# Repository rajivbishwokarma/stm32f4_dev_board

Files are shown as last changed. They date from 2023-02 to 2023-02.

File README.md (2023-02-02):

# STM32F405RGT6 Development Board KiCAD Design Files

## Introduction
This repository contains a development board for STM32F405RGT6 microcontroller.

## Circuit Schematic
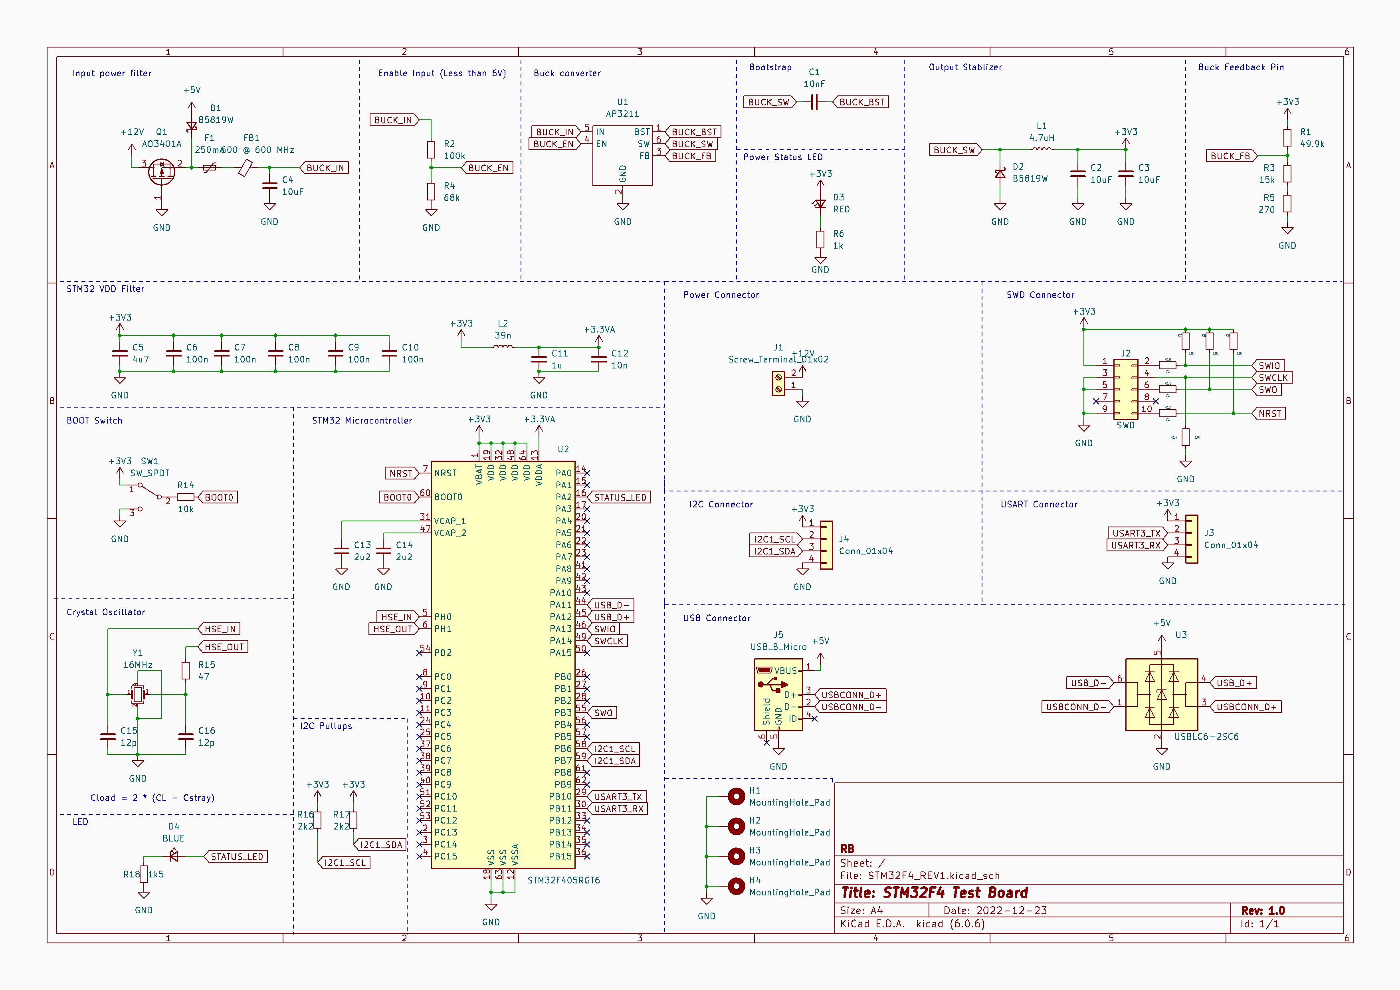
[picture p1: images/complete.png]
Circuit Schematic


## PCB and 3D View
<p align="left">
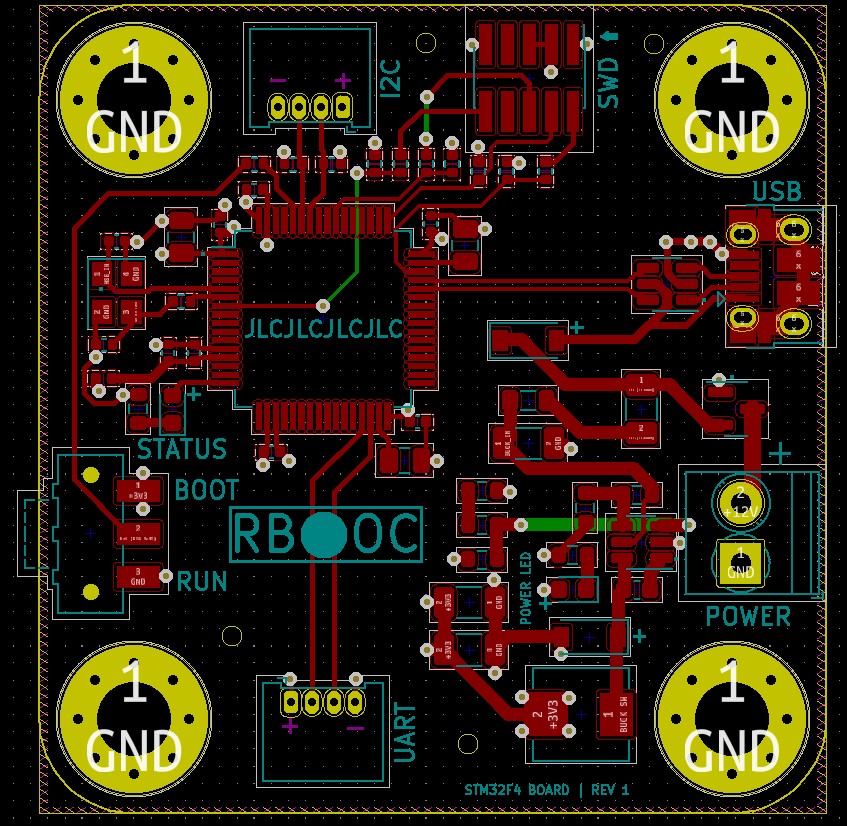
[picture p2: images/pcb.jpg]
    
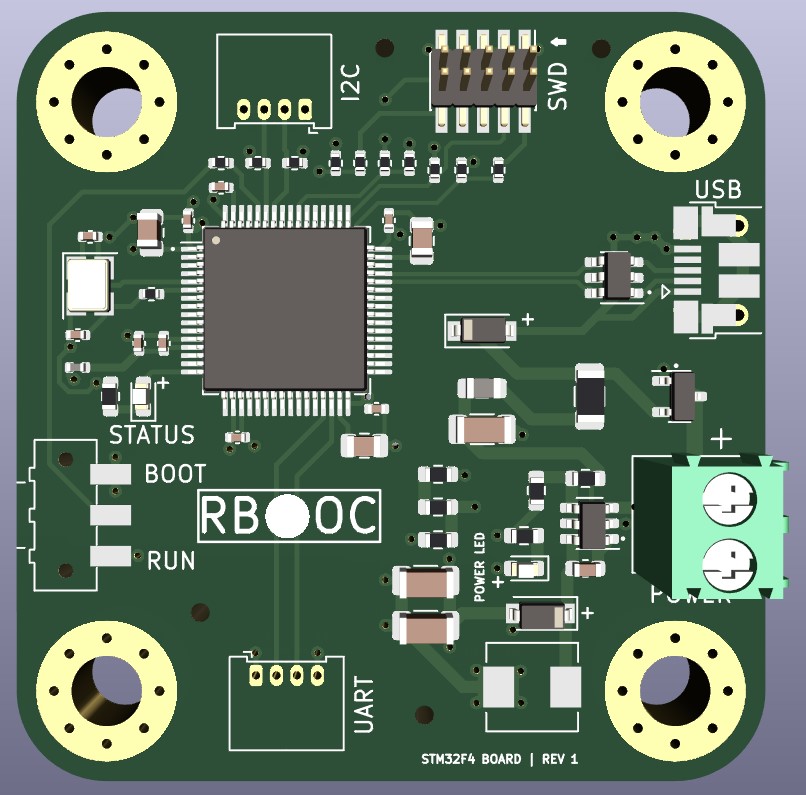
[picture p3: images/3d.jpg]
    
</p>

## Microcontroller
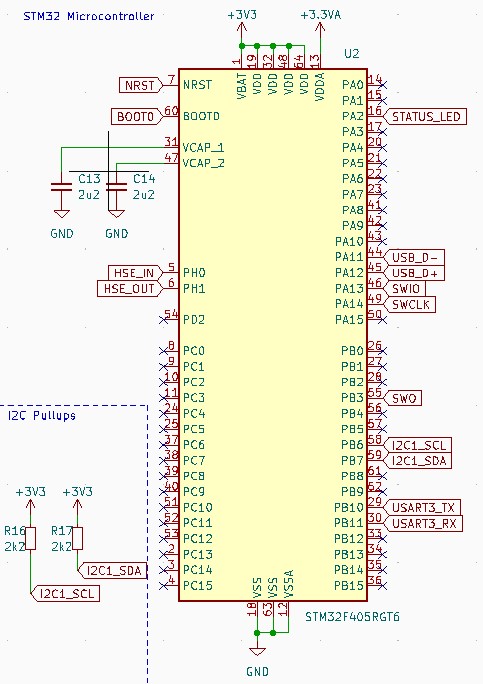
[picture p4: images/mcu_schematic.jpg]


## Buck Converter and SWD Interface
<p align="left">
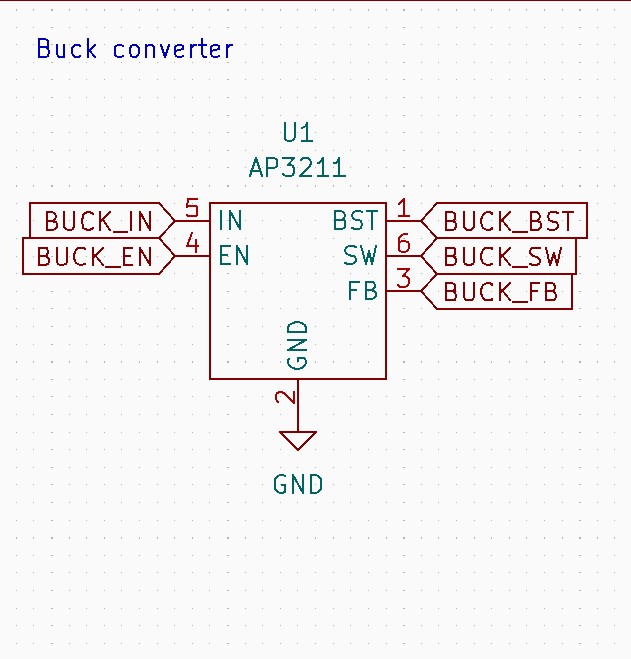
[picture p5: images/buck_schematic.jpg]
    
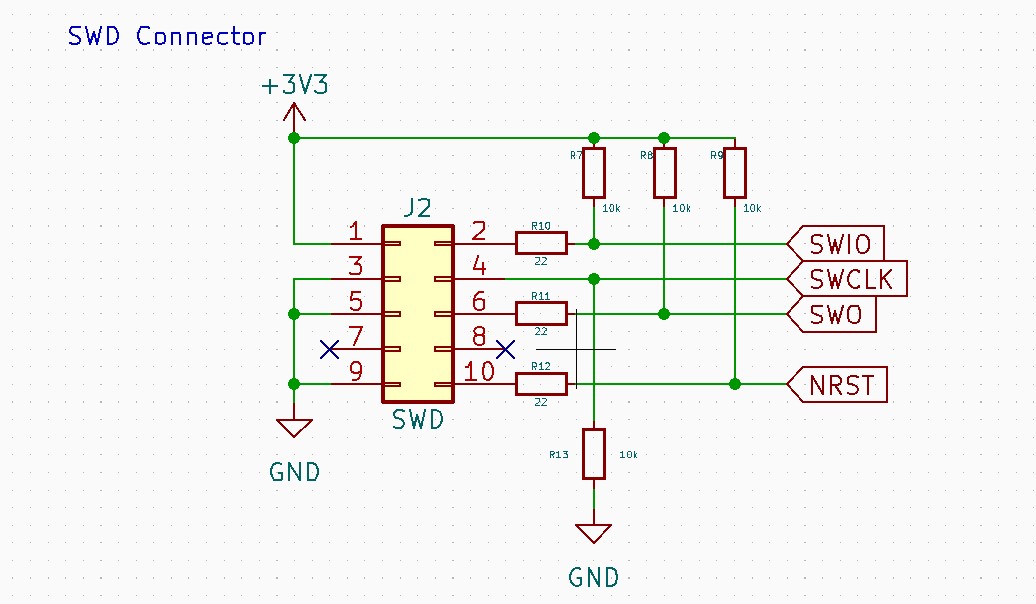
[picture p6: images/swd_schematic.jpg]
    
</p>

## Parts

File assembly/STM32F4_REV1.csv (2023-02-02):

Comment | Designator | Footprint | LCSC
10nF | C1 | Capacitor_SMD:C_0603_1608Metric | C282516
1u | C11 | Capacitor_SMD:C_0402_1005Metric | C106254
10n | C12 | Capacitor_SMD:C_0402_1005Metric | C783637
2u2 | C13,C14 | Capacitor_SMD:C_0805_2012Metric | C105486
12p | C15,C16 | Capacitor_SMD:C_0402_1005Metric | C147414
10uF | C2,C3,C4 | Capacitor_SMD:C_1206_3216Metric | C165101
4u7 | C5 | Capacitor_SMD:C_0805_2012Metric | C131057
100n | C6,C7,C8,C9,C10 | Capacitor_SMD:C_0402_1005Metric | C106204
B5819W | D1,D2 | Diode_SMD:D_SOD-123 | C908224
RED | D3 | LED_SMD:LED_0603_1608Metric | C84263
BLUE | D4 | LED_SMD:LED_0603_1608Metric | C375575
250mA | F1 | Fuse:Fuse_1206_3216Metric | C182446
600 @ 600 MHz | FB1 | Inductor_SMD:L_0805_2012Metric | C82155
MountingHole_Pad | H1,H2,H3,H4 | MountingHole:MountingHole_4.3mm_M4_Pad_Via
Screw_Terminal_01x02 | J1 | TerminalBlock_Phoenix:TerminalBlock_Phoenix_PT-1,5-2-3.5-H_1x02_P3.50mm_Horizontal | C395882
SWD | J2 | Connector_PinHeader_1.27mm:PinHeader_2x05_P1.27mm_Vertical_SMD | C5142425
Conn_01x04 | J3,J4 | Connector_Molex:Molex_PicoBlade_53048-0410_1x04_P1.25mm_Horizontal
USB_B_Micro | J5 | Connector_USB:USB_Micro-B_Amphenol_10103594-0001LF_Horizontal | C598519
10uH | L1 | Inductor_SMD:L_Sunlord_MWSA0518_5.4x5.2mm | C408349
39n | L2 | Inductor_SMD:L_0402_1005Metric | C142231
AO3401A | Q1 | Package_TO_SOT_SMD:SOT-23 | C347476
49.9k | R1 | Resistor_SMD:R_0603_1608Metric | C881902
22 | R10,R11,R12 | Resistor_SMD:R_0402_1005Metric | C102894
47 | R15 | Resistor_SMD:R_0402_1005Metric | C11930
2k2 | R16,R17 | Resistor_SMD:R_0402_1005Metric | C114762
1k5 | R18 | Resistor_SMD:R_0603_1608Metric | C140221
100k | R2 | Resistor_SMD:R_0603_1608Metric | C217279
15k | R3 | Resistor_SMD:R_0603_1608Metric | C285208
68k | R4 | Resistor_SMD:R_0603_1608Metric | C177676
270 | R5 | Resistor_SMD:R_0603_1608Metric | C209092
1k | R6 | Resistor_SMD:R_0603_1608Metric | C216905
10k | R7,R8,R9,R13,R14 | Resistor_SMD:R_0402_1005Metric | C406733
SW_SPDT | SW1 | Button_Switch_SMD:SW_SPDT_CK-JS102011SAQN | C221660
AP3211 | U1 | Package_TO_SOT_SMD:SOT-23-6 | C154863
STM32F405RGT6 | U2 | Package_QFP:LQFP-64_10x10mm_P0.5mm | C15742
USBLC6-2SC6 | U3 | Package_TO_SOT_SMD:SOT-23-6 | C7519
16MHz | Y1 | Crystal:Crystal_SMD_3225-4Pin_3.2x2.5mm | C13738

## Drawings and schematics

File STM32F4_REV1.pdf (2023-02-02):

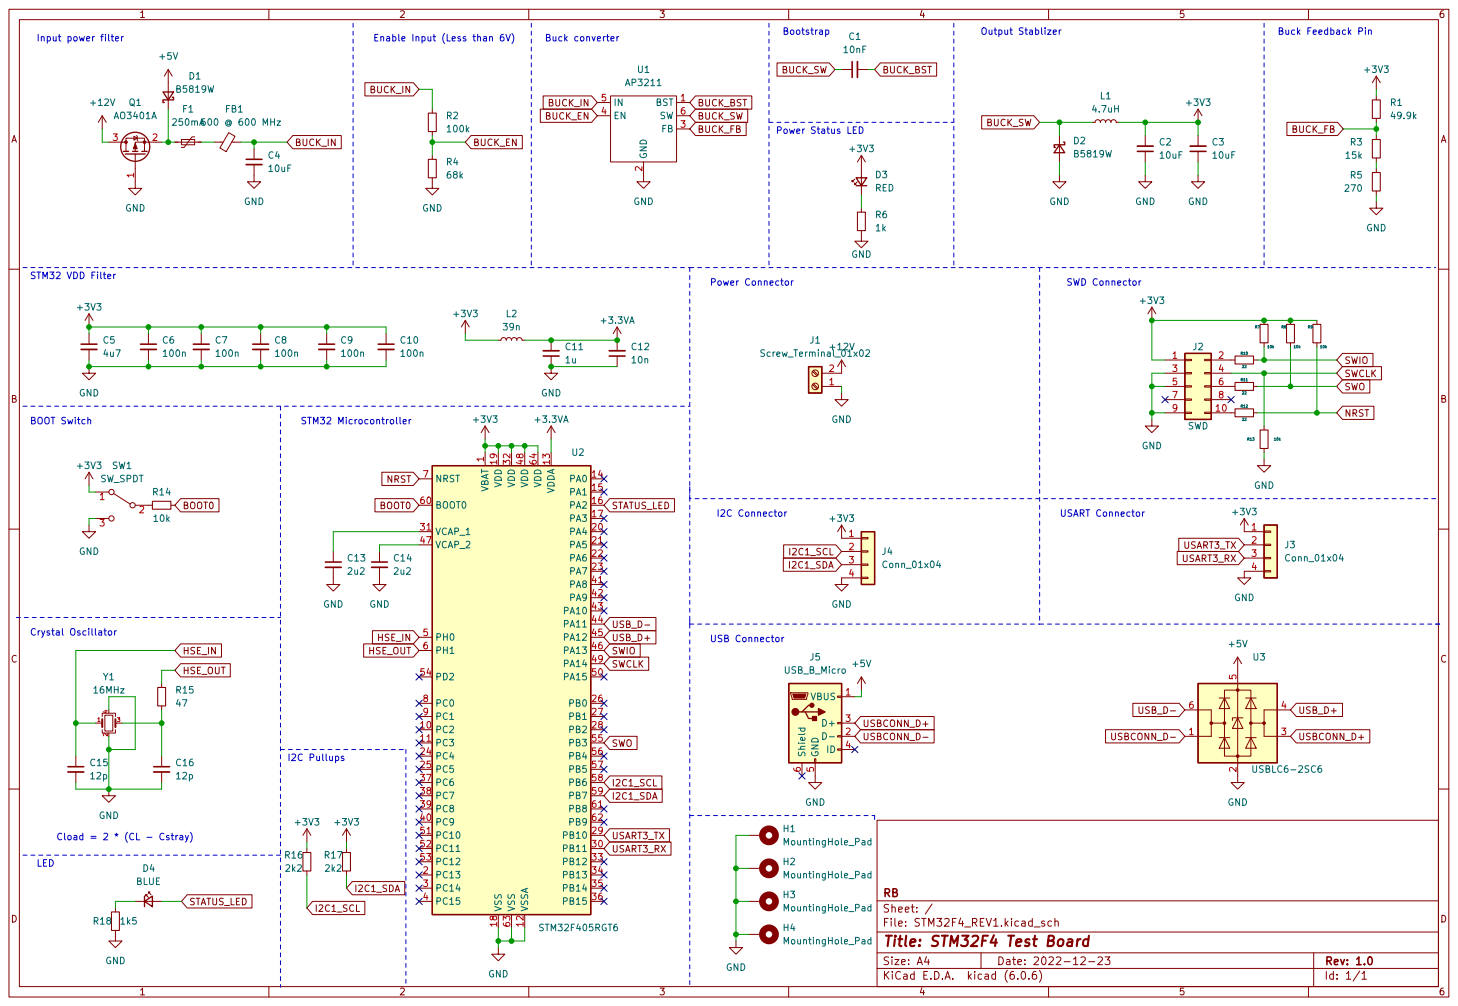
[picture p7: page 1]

USART Connector SWD Connector Buck converter

D3 RED
I2C Connector Power Connector USB Connector

1 PC2 10 PC3 11 VSSA 12 VDDA 13 PA0 14 PA1 15 PA2 16 PA3 17 VSS 18 VDD 19 PC13 2 PA4 20 PA5 21 PA6 22 PA7 23 PC4 24 PC5 25 PB0 26 PB1 27 PB2 28 PB10 29 PC14 3 PB11 30 VCAP_1 31 VDD 32 PB12 33 PB13 34 PB14 35 PB15 36 PC6 37 PC7 38 PC8 39 PC15 4 PC9 40 PA8 41 PA9 42 PA10 43 PA11 44 PA12 45 PA13 46 VCAP_2 47 VDD 48 PA14 49 PH0 5 PA15 50 PC10 51 PC11 52 PC12 53 PD2 54 PB3 55 PB4 56 PB5 57 PB6 58 PB7 59 PH1 6 BOOT0 60 PB8 61 PB9 62 VSS 63 VDD 64 NRST 7 PC0 8 PC1 9 U2 STM32F405RGT6 GND

Id: 1/1 Title: STM32F4 Test Board

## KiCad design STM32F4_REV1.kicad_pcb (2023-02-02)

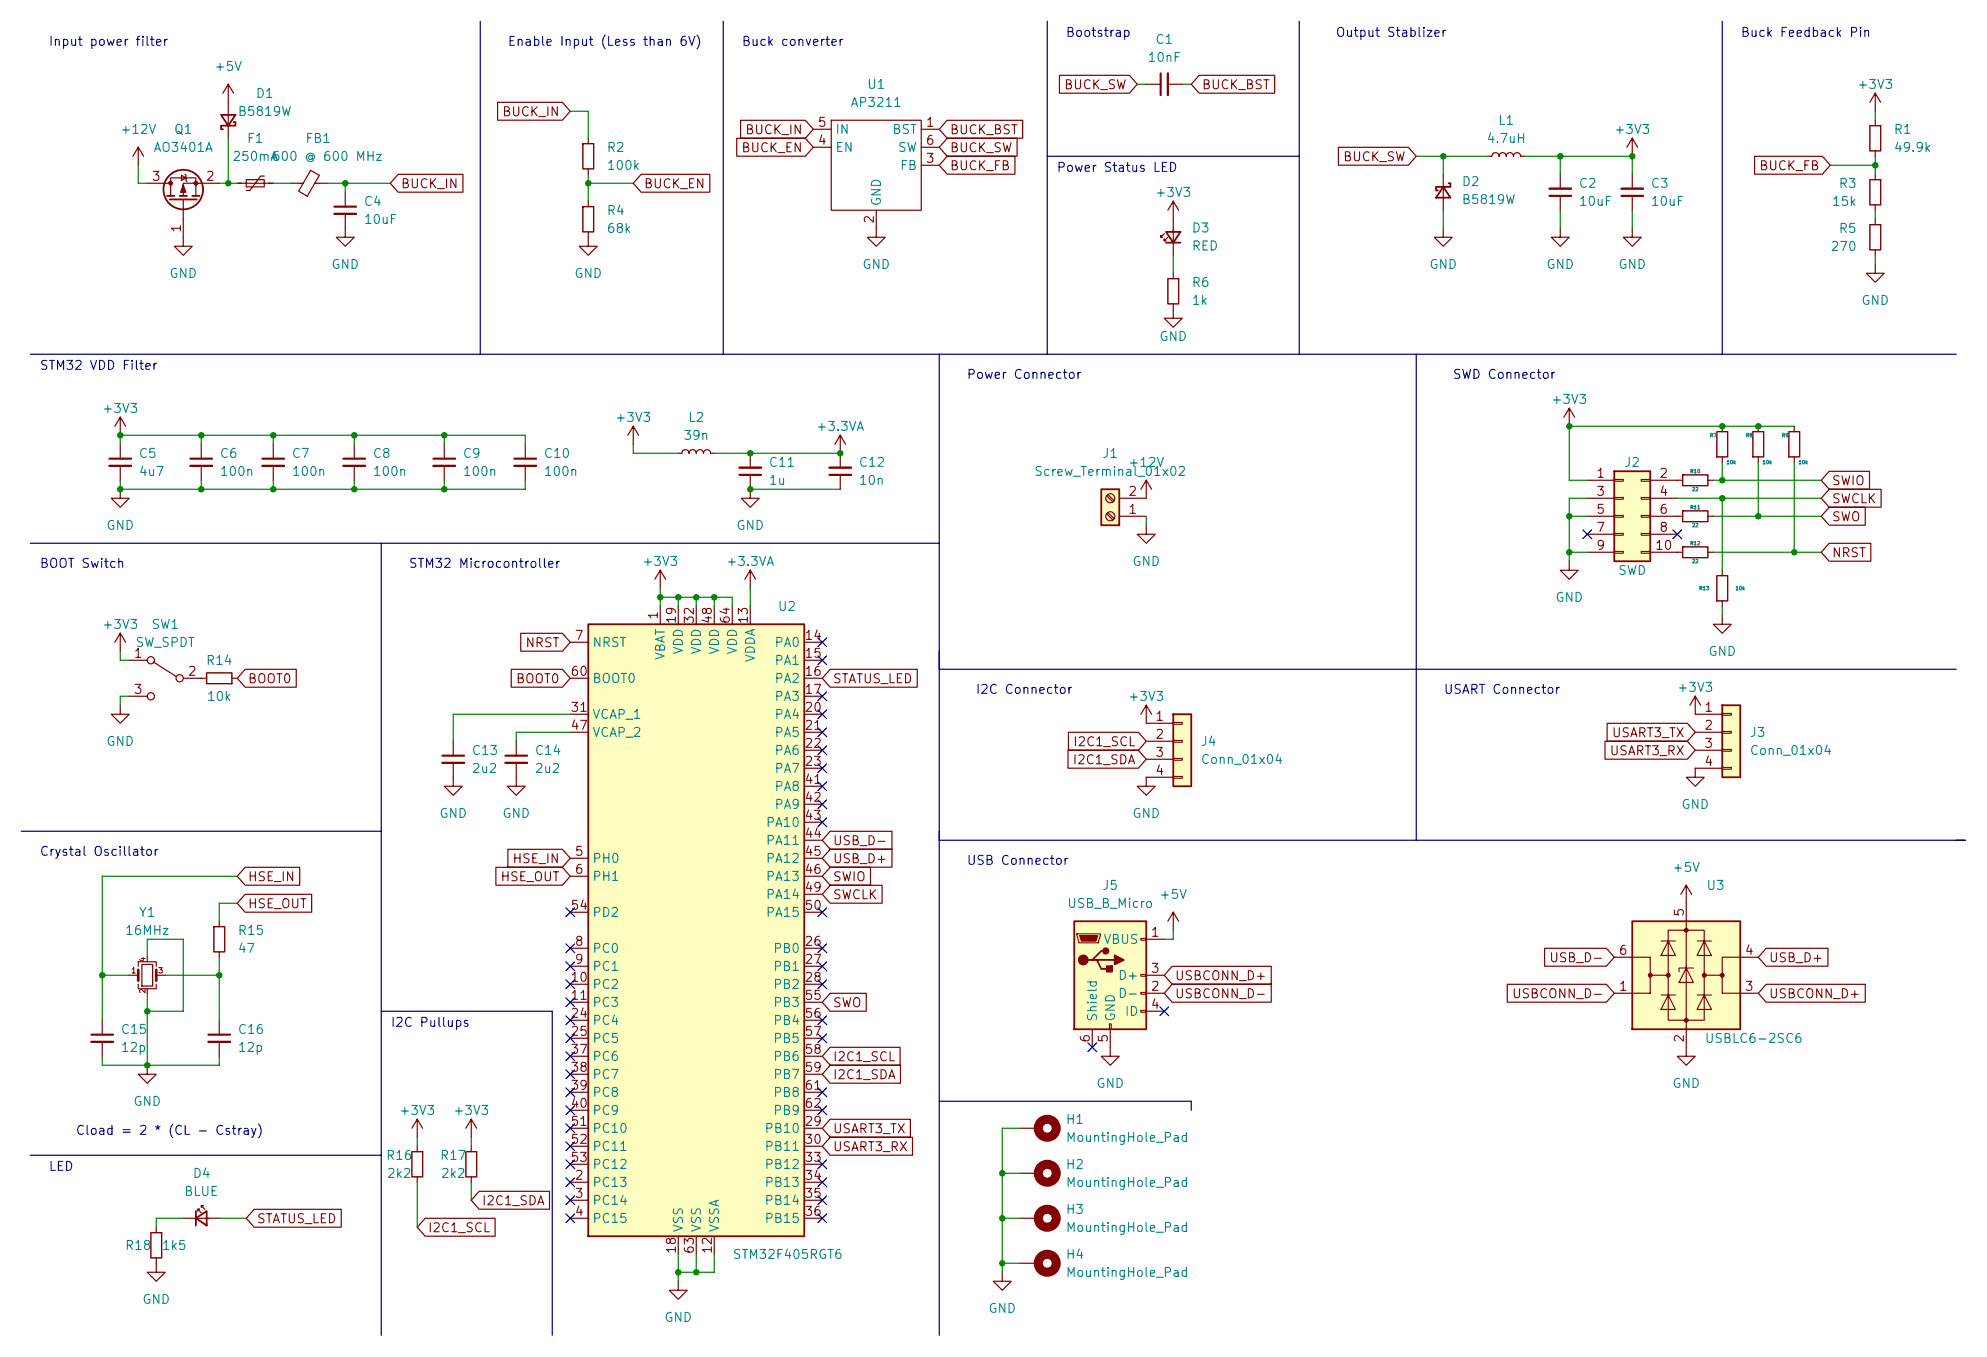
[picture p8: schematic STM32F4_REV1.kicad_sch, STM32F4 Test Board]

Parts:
C1: 10nF; C_0603_1608Metric; LCSC Part # C282516
C2, C3, C4: 10uF; C_1206_3216Metric; LCSC Part # C165101
C5: 4u7; C_0805_2012Metric; LCSC Part # C131057
C6, C7, C8, C9, C10: 100n; C_0402_1005Metric; LCSC Part # C106204
C11: 1u; C_0402_1005Metric; LCSC Part # C106254
C12: 10n; C_0402_1005Metric; LCSC Part # C783637
C13, C14: 2u2; C_0805_2012Metric; LCSC Part # C105486
C15, C16: 12p; C_0402_1005Metric; LCSC Part # C147414
D1, D2: B5819W; D_SOD-123; LCSC Part # C908224
D3: RED; LED_0603_1608Metric; LCSC Part # C84263
D4: BLUE; LED_0603_1608Metric; LCSC Part # C375575
F1: 250mA; Fuse_1206_3216Metric; LCSC Part # C182446
FB1: 600 @ 600 MHz; L_0805_2012Metric; LCSC Part # C82155
H1, H2, H3, H4: MountingHole_Pad; MountingHole_4.3mm_M4_Pad_Via
J1: Screw_Terminal_01x02; TerminalBlock_Phoenix_PT-1,5-2-3.5-H_1x02_P3.50mm_Horizontal; LCSC Part # C395882
J2: SWD; PinHeader_2x05_P1.27mm_Vertical_SMD; LCSC Part # C5142425
J3, J4: Conn_01x04; Molex_PicoBlade_53048-0410_1x04_P1.25mm_Horizontal
J5: USB_B_Micro; USB_Micro-B_Amphenol_10103594-0001LF_Horizontal; LCSC Part # C598519
L1: 4.7uH; L_Sunlord_MWSA0518_5.4x5.2mm; LCSC Part # C408349
L2: 39n; L_0402_1005Metric; LCSC Part # C142231
Q1: AO3401A; SOT-23; LCSC Part # C347476
R1: 49.9k; R_0603_1608Metric; LCSC Part # C365177
R2: 100k; R_0603_1608Metric; LCSC Part # C217279
R3: 15k; R_0603_1608Metric; LCSC Part # C285208
R4: 68k; R_0603_1608Metric; LCSC Part # C177676
R5: 270; R_0603_1608Metric; LCSC Part # C209092
R6: 1k; R_0603_1608Metric; LCSC Part # C216905
R7, R8, R9, R13, R14: 10k; R_0402_1005Metric; LCSC Part # C406733
R10, R11, R12: 22; R_0402_1005Metric; LCSC Part # C102894
R15: 47; R_0402_1005Metric; LCSC Part # C11930
R16, R17: 2k2; R_0402_1005Metric; LCSC Part # C114762
R18: 1k5; R_0603_1608Metric; LCSC Part # C140221
SW1: SW_SPDT; SW_SPDT_CK-JS102011SAQN; LCSC Part # C221660
U1: AP3211; SOT-23-6; LCSC Part # C14259
U2: STM32F405RGT6; LQFP-64_10x10mm_P0.5mm; LCSC Part # C15742
U3: USBLC6-2SC6; SOT-23-6; LCSC Part # C7519
Y1: 16MHz; Crystal_SMD_3225-4Pin_3.2x2.5mm; LCSC Part # C13738

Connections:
+3.3VA: C11.2, C12.2, L2.2, U2.13 (VDDA)
+3V3: C2.2, C3.2, C5.1, C6.1, C7.1, C8.1, C9.1, C10.1, D3.2 (A), J2.1, J3.1, J4.1, L1.2, L2.1, R1.1, R7.2, R8.2, R9.2, R16.1, R17.1, SW1.1 (A), U2.1 (VBAT), U2.19 (VDD), U2.32 (VDD), U2.48 (VDD), U2.64 (VDD)
+5V: D1.2 (A), J5.1 (VBUS), U3.5 (VBUS)
+12V: J1.2, Q1.3 (D)
BOOT0: R14.1, U2.60 (BOOT0)
BUCK_BST: C1.2, U1.1 (BST)
BUCK_EN: R2.2, R4.1, U1.4 (EN)
BUCK_FB: R1.2, R3.1, U1.3 (FB)
BUCK_IN: C4.1, FB1.2, R2.1, U1.5 (IN)
BUCK_SW: C1.1, D2.1 (K), L1.1, U1.6 (SW)
GND: C2.1, C3.1, C4.2, C5.2, C6.2, C7.2, C8.2, C9.2, C10.2, C11.1, C12.1, C13.2, C14.2, C15.2, C16.2, D2.2 (A), H1.1, H2.1, H3.1, H4.1, J1.1, J2.3, J2.5, J2.9, J3.4, J4.4, J5.5 (GND), Q1.1 (G), R4.2, R5.2, R6.2, R13.1, R18.2, SW1.3 (C), U1.2 (GND), U2.12 (VSSA), U2.18 (VSS), U2.63 (VSS), U3.2 (GND), Y1.2, Y1.4
HSE_IN: C15.1, U2.5 (PH0), Y1.1
HSE_OUT: R15.1, U2.6 (PH1)
I2C1_SCL: J4.2, R16.2, U2.58 (PB6)
I2C1_SDA: J4.3, R17.2, U2.59 (PB7)
NRST: R9.1, R12.2, U2.7 (NRST)
unnamed: C13.1, U2.31 (VCAP_1)
unnamed: C14.1, U2.47 (VCAP_2)
unnamed: C16.1, R15.2, Y1.3
unnamed: D1.1 (K), F1.1, Q1.2 (S)
unnamed: D3.1 (K), R6.1
unnamed: D4.1 (K), R18.1
unnamed: F1.2, FB1.1
unnamed: J2.2, R10.1
unnamed: J2.6, R11.1
unnamed: J2.10, R12.1
unnamed: R3.2, R5.1
unnamed: R14.2, SW1.2 (B)
STATUS_LED: D4.2 (A), U2.16 (PA2)
SWCLK: J2.4, R13.2, U2.49 (PA14)
SWIO: R7.1, R10.2, U2.46 (PA13)
SWO: R8.1, R11.2, U2.55 (PB3)
USART3_RX: J3.3, U2.30 (PB11)
USART3_TX: J3.2, U2.29 (PB10)
USBCONN_D+: J5.3 (D+), U3.3 (I/O2)
USBCONN_D-: J5.2 (D-), U3.1 (I/O1)
USB_D+: U2.45 (PA12), U3.4 (I/O2)
USB_D-: U2.44 (PA11), U3.6 (I/O1)

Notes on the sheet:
STM32 VDD Filter
Cload = 2 * (CL - Cstray)
I2C Pullups
STM32 Microcontroller
Input power filter
USART Connector
I2C Connector
Crystal Oscillator
SWD Connector
Buck Feedback Pin
Buck converter
Power Status LED
Output Stablizer
Bootstrap
LED
Enable Input (Less than 6V)
USB Connector
Power Connector
BOOT Switch

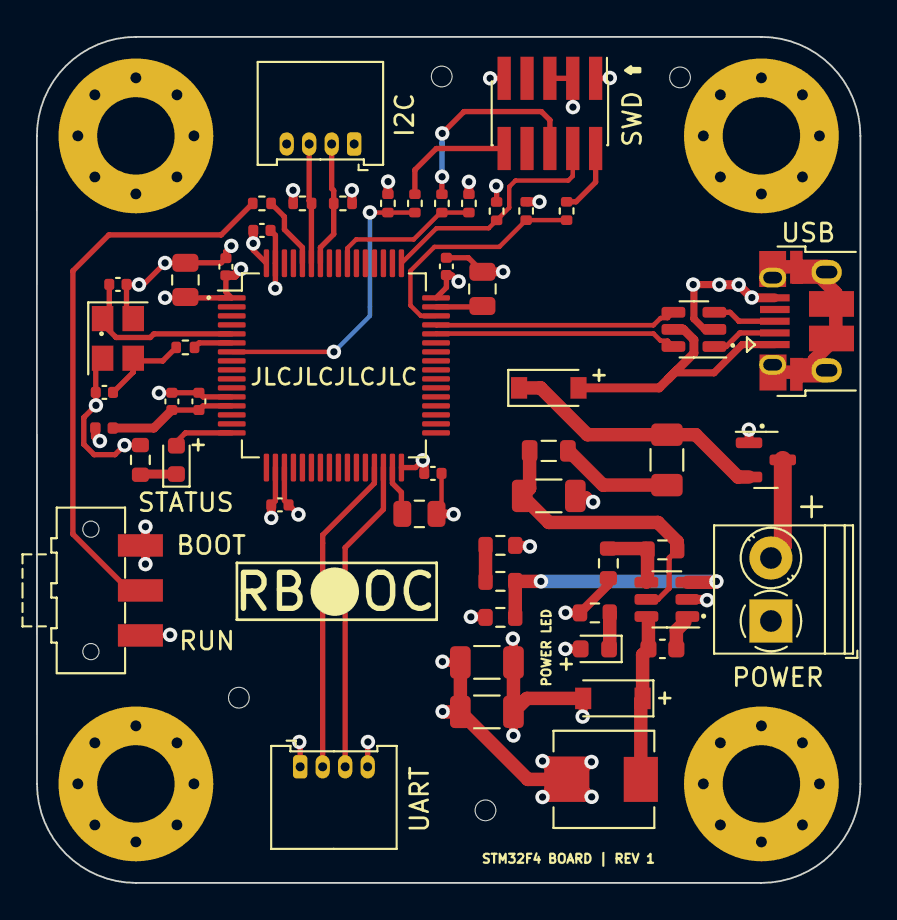
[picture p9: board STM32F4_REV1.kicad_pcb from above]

Board: 4 copper layers, 45.8 x 47.0 mm, 57 parts (0 on the bottom side), 38 nets.

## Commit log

2023-02-02 Add complete files
    [STM32F4_REV1-B_Cu.gbr, STM32F4_REV1-B_Mask.gbr, STM32F4_REV1-B_Paste.gbr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]
2023-02-02 Add schematic PDF and images
